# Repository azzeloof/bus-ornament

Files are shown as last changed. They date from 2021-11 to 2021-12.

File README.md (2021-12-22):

# London Bus Ornament
 A PCB holiday ornament with lots of blinking LEDs!

## Hardware
The board consists of twelve reverse-mounted LEDs [charlieplexed](https://en.wikipedia.org/wiki/Charlieplexing) and hooked up to an ATtiny85. Each LED is individually addressable, even though only four of the ATtiny's pins are being used (Charlieplexing is magic)! The board also has a pushbutton for switching between modes. The ornament is powered via two CR2025 batteries which feed a 3.3V buck converter.

The design works as-is, but there's an issue. When the programmer is hooked up, it needs to be set to not power the PCB. If it does power the boar,d it will immediatley fry the buck converter. To get around this, I cut the VCC trace to the ICSP and connected that pin to the unused pin of the power switch via a bodged wire. 

## Firmware
The ATtiny is programmed using the PlatformIO framework. Before programming, you need to write an Arduino bootloader to the chip using the Arduino IDE. When burning the bootloader, here are the settings we used:

+ Chip: "ATtiny85" (from the ATtiny Core board library)
+ Clock: "8 MHz (internal)"
+ B.O.D: "B.O.D. Disabled"
+ Timer 1 Clock: "CPU"
+ LTO (1.6.11+ only): "Disabled"

The code is adapted from the wonderful work of David Johnson-Davies, published at http://www.technoblogy.com/show?2H0K.

To program the chips, we used SparkFun's [Pocket AVR Programmer](https://www.sparkfun.com/products/9825), but you should be able to use any programmer compatibe with the ATtiny85 (or just use an Arduino Uno!).

## Version History
Release 1.0 will represent the bus ornaments as we initially made and distributed them. Once it is released, maybe we'll improve some stuff (but any hardware improvements will be untested).

## Warning
Electricity creates heat, and excess heat around something like a Christmas tree can cause big problems. Use at your own risk! The designs here have only been minimally tested and are absolutley not guarenteed to be safe.

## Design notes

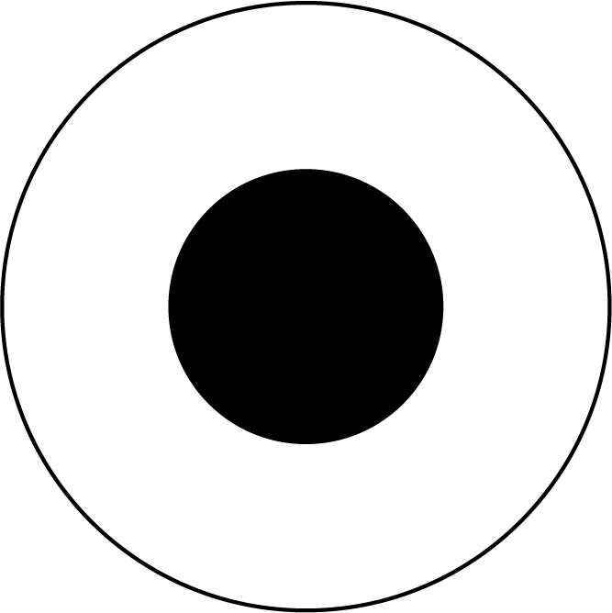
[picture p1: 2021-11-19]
hardware/artwork/wheel_hub.png

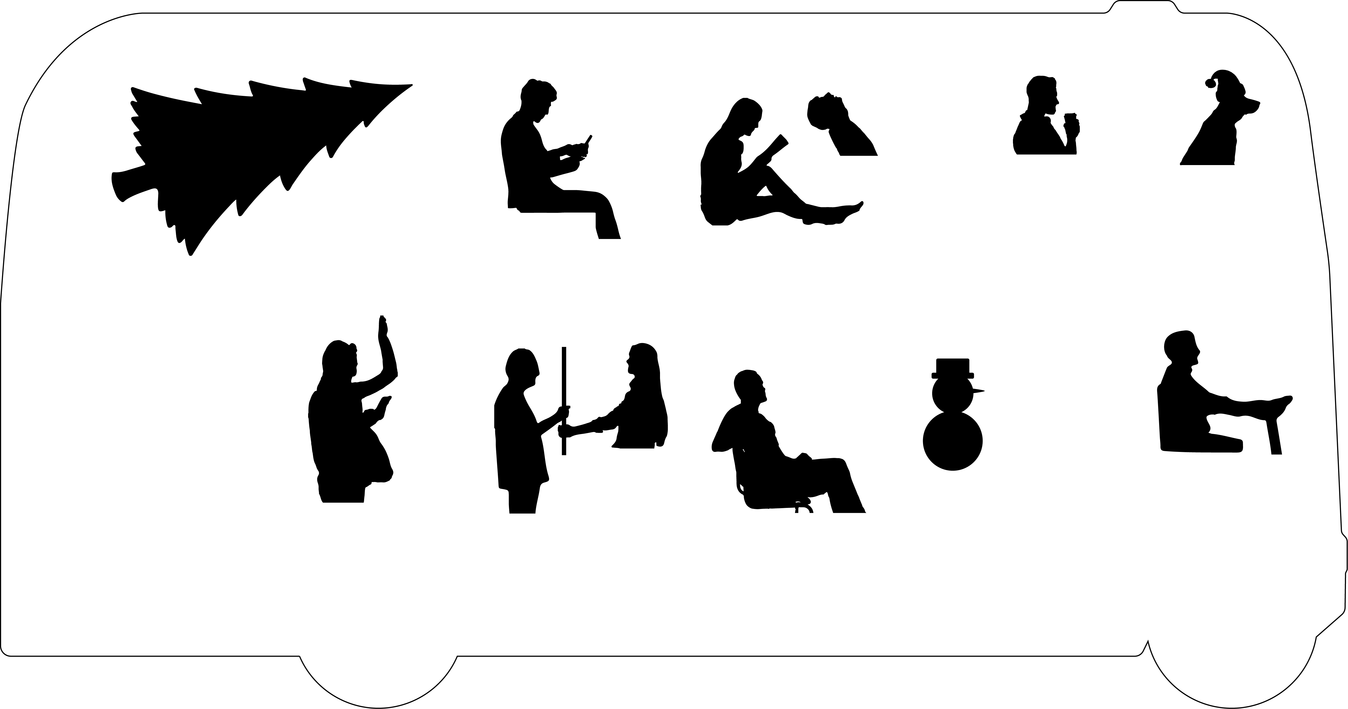
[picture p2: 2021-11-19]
hardware/artwork/inner_copper_art.png

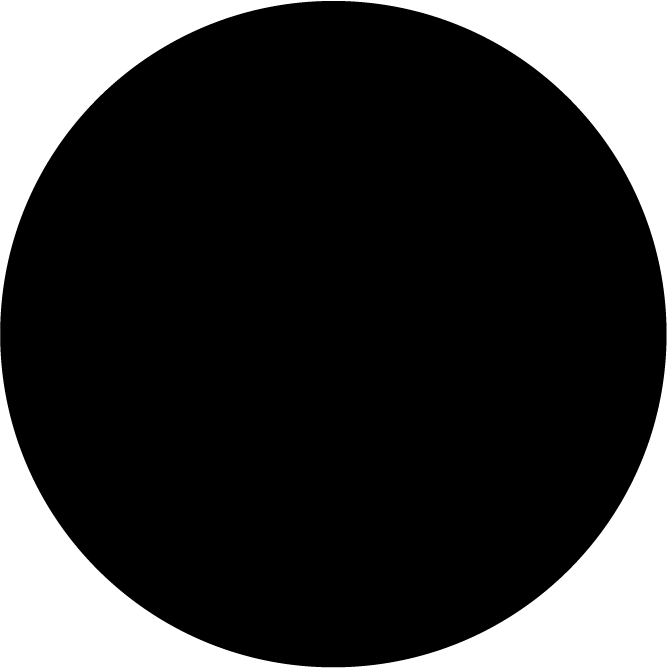
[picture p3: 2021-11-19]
hardware/artwork/wheel.png

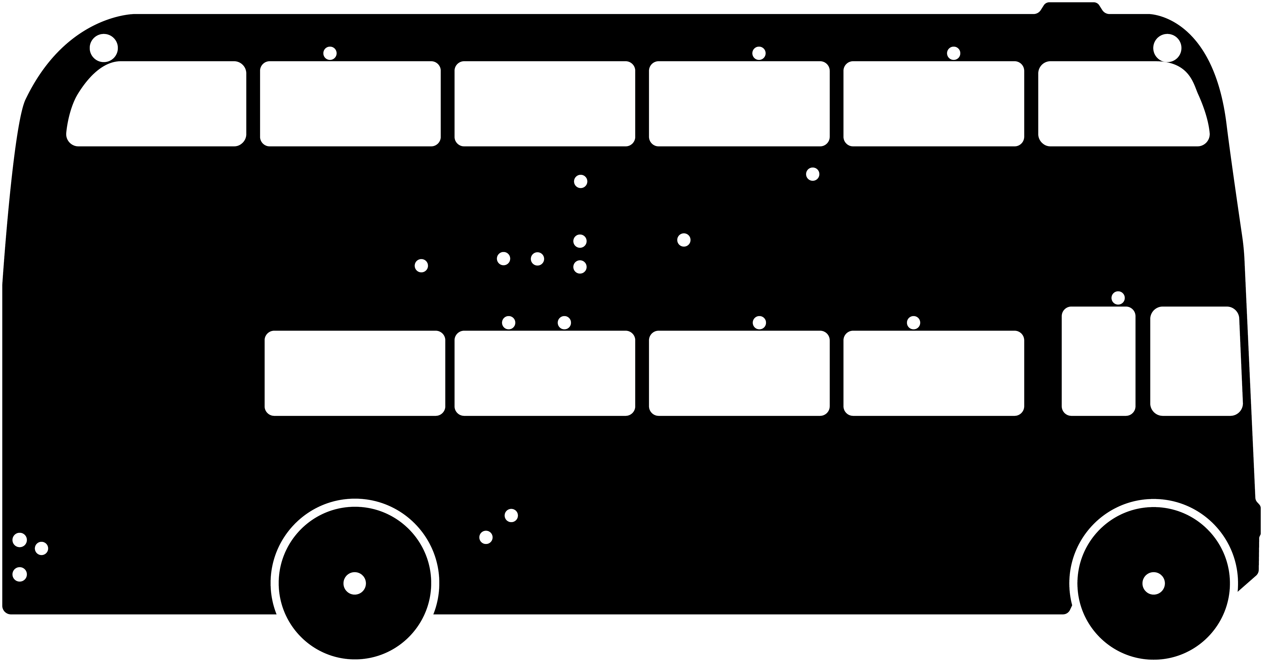
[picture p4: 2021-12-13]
hardware/artwork/copper_front.png

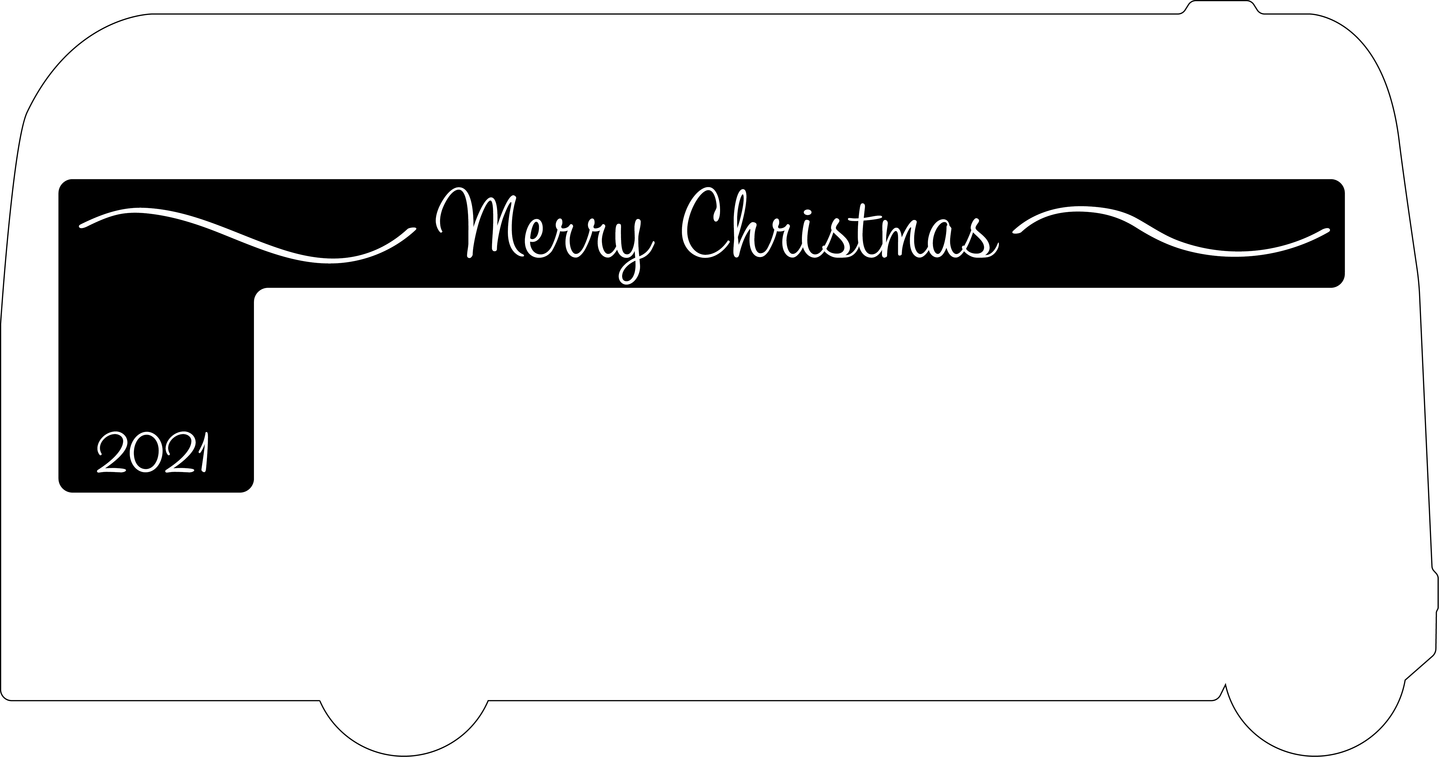
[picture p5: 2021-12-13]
hardware/artwork/silkscreen_front.png

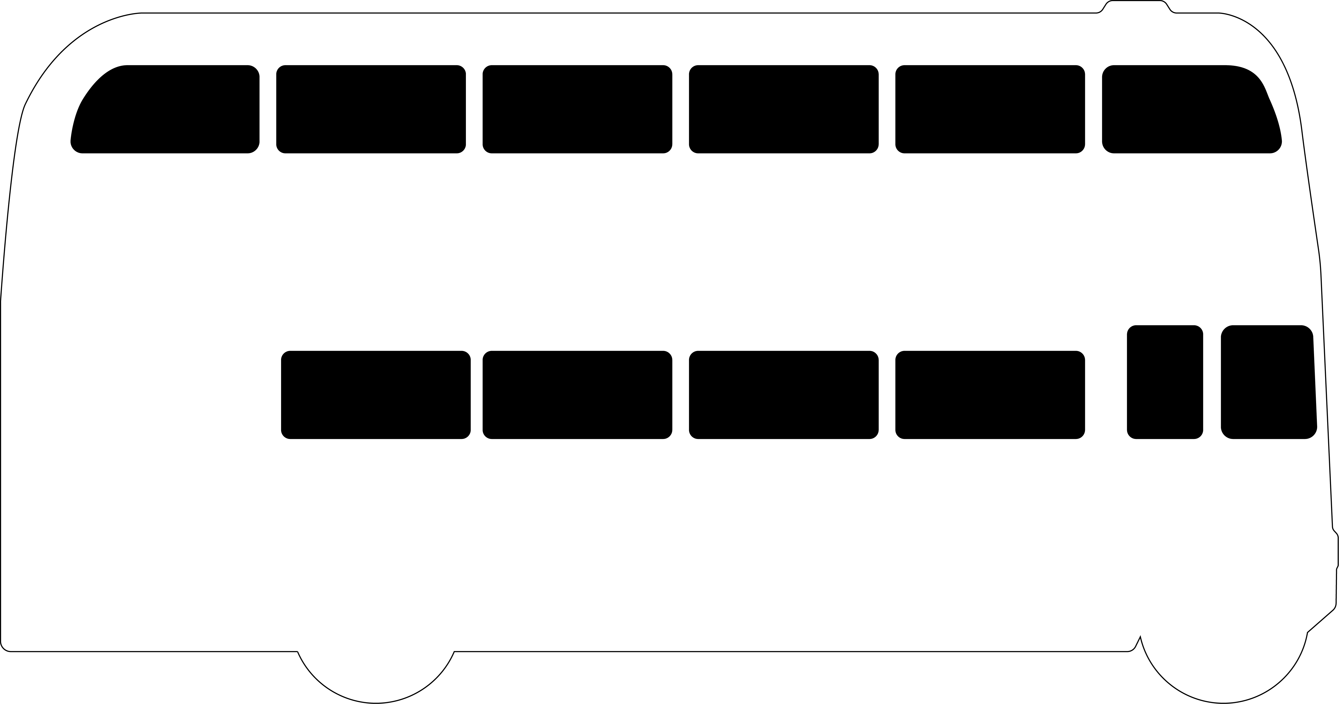
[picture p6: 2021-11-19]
hardware/artwork/mask_front.png

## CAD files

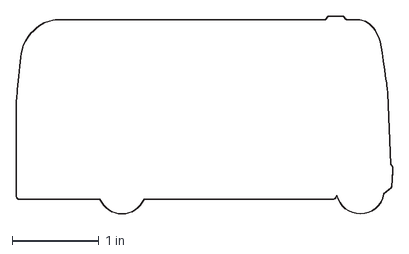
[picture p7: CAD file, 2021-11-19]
hardware/artwork/edge.dxf
4.33 x 2.28 in

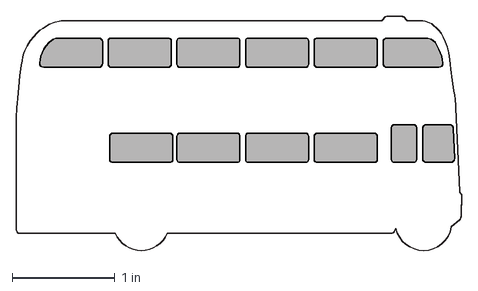
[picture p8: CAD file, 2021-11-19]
hardware/artwork/mask_front.dxf
4.33 x 2.28 in

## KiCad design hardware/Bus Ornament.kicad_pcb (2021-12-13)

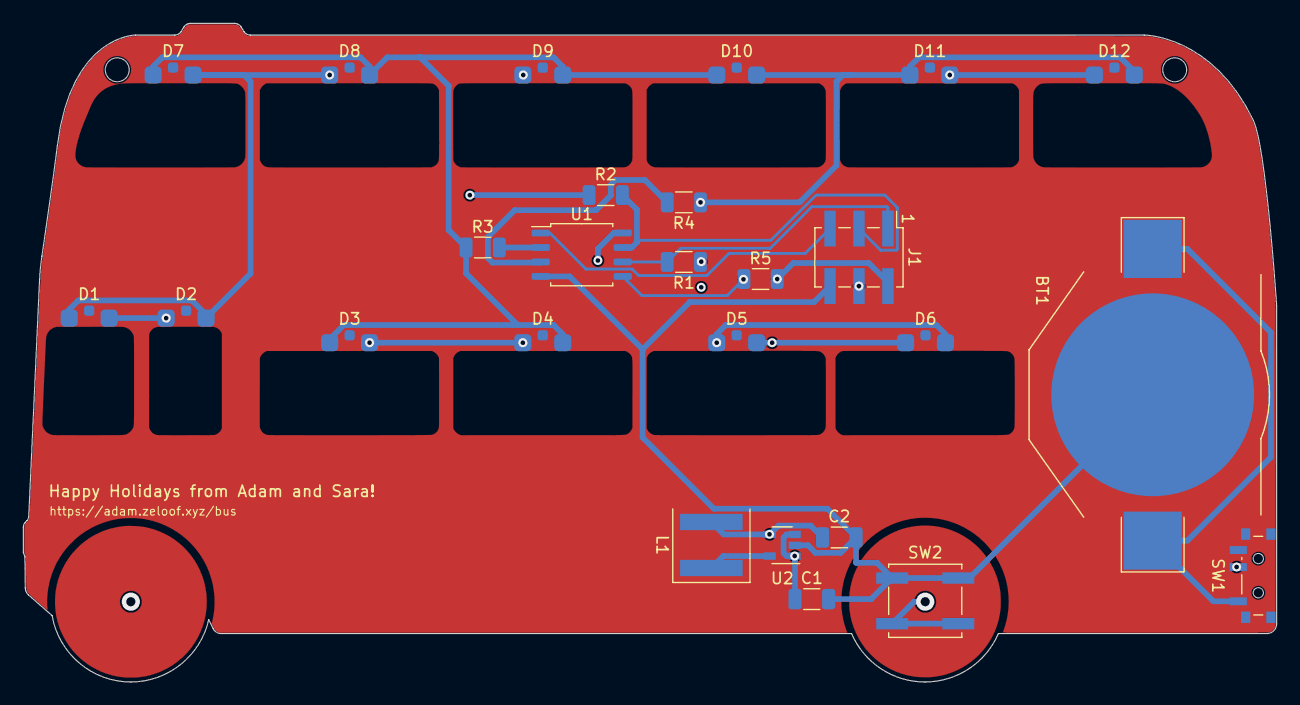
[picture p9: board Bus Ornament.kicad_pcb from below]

Board: 4 copper layers, 110.0 x 57.8 mm, 26 parts (26 on the bottom side), 15 nets.

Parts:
BT1: Battery; BatteryHolder_Keystone_3002_1x2032
C1, C2: C; C_1206_3216Metric
D1, D2, D3, D4, D5, D6, D7, D8, D9, D10, D11, D12: LED; IN-S121AS
J1: Conn_02x03_Odd_Even; PinHeader_2x03_P2.54mm_Vertical_SMD
L1: L; L_Coilcraft_XAL60xx_6.36x6.56mm
R1, R2, R3, R4, R5: R_US; R_1206_3216Metric
SW1: SW_SPST; SW_SPDT_PCM12
SW2: SW_Push; SW_Push_1P1T_NO_CK_KSC6xxJ
U1: ATtiny85-20PU; SOIC-8_5.23x5.23mm_P1.27mm
U2: TPS62203DBV; SOT-23-5

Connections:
+BATT: BT1.1, SW1.1
GND: BT1.2, C1.2, C2.2, J1.6, SW2.2, U1.4, U2.2
MISO: J1.1, R1.2, U1.6
MOSI: J1.4, R5.1, SW2.1, U1.5
unnamed: C1.1, SW1.2, U2.1, U2.3
unnamed: D1.1, D2.2, D7.2, D8.1, D11.2, D12.1, R2.1
unnamed: D1.2, D2.1, D3.2, D4.1, D5.2, D6.1, R1.1
unnamed: D3.1, D4.2, D7.1, D8.2, D9.2, D10.1, R3.1
unnamed: D5.1, D6.2, D9.1, D10.2, D11.1, D12.2, R4.1
unnamed: L1.1, U2.5
unnamed: R3.2, U1.2
unnamed: R4.2, U1.3
RST: J1.5, U1.1
SCK: J1.3, R2.2, U1.7
VCC: C2.1, J1.2, L1.2, R5.2, U1.8, U2.4

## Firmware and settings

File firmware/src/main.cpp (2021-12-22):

/*
 * London Bus Christmas Ornament
 * 
 * Sara Adkins & Adam Zeloof - November 2021
 * 
 * PWM code adapted from David Johnson-Davies - www.technoblogy.com - 19th February 2017
 * http://www.technoblogy.com/show?2H0K
 */

#include "Arduino.h"
#include "modeButton.h"
#include "leds.h"
#include "scrollingSequentialAnimation.h"
#include "singleSequentialAnimation.h"
#include "randomAnimation.h"

// Timer/Counter1 overflow interrupt
ISR(TIM1_COMPA_vect) {
  static uint8_t row, ramp, column, bits, colbit;
  ramp = (ramp+1) & 0x3F;             // Count from 0 to 63
  if (ramp == 0) {
    bits = 0x07; //0000111                    // All on
    column = (column + 1) & 0x03; // Count from 0 to 3
    row = column * 3;               //0 3 6 9
    colbit = 1<<(column+0); // 0b0001 0b0010 0b0100 0b1000
  }

  //check if check col has reached its ramp
  if (Level[row] == ramp) bits = bits & 0x06; // 00000110, mask out pos 0
  if (Level[row+1] == ramp) bits = bits & 0x05; // 00000101, mask out pos 1
  if (Level[row+2] == ramp) bits = bits & 0x03; // 00000011, mask out pos 2
  
  uint8_t mask = colbit - 1; 
  
  uint8_t outputs = (bits & mask) | (bits & ~mask)<<1;
  DDRB = (outputs | colbit) << 1;
  PORTB = (outputs) << 1;
}

void setup() {
  // Set up Timer/Counter1 to multiplex the LEDs
  TCCR1 = 1<<CTC1 | 2<<CS10;          // Divide by 2
  GTCCR = 0;                          // No PWM
  OCR1A = 0;
  OCR1C = 250-1;                      // 16kHz
  TIMSK = TIMSK | 1<<OCIE1A;          // Compare Match A interrupt

  setupButton();
  setupLeds();
}

void allOnProgram()
{
  allOn();
  checkButton();
}

void allOffProgram()
{
  clearLeds();
  checkButton();
}

uint32_t delayMS = 4000;

void loop () {
  switch(mode) {   
    case 0:
      randomProgram(delayMS);
      break; 
    case 1:
      allOnProgram();
      break;
    case 2:
      singleSequentialProgram(delayMS);
      break;
    //case 3:
    //  scrollingSequentialProgram(4, delayMS);
    //  break;
    default:
      allOffProgram();
      break;
  }
}

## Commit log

2021-11-19 Design completed
    [Bus Ornament.kicad_pcb, Bus Ornament.sch, edge.dxf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]
2021-11-19 Generated gerbers
    [Bus Ornament-B_Cu.gbl, Bus Ornament-B_Mask.gbs, Bus Ornament-B_Paste.gbp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]
2021-11-19 Repo Reorg and Cleanup
    [Bus Ornament-B_Cu.gbl, Bus Ornament-B_Mask.gbs, Bus Ornament-B_Paste.gbp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]
2021-11-26 Firmware written but untested
    [Bus Ornament.sch]
2021-12-13 Crated front fill, ordered new boards
    [Bus Ornament-B_Cu.gbl, Bus Ornament-B_Mask.gbs, Bus Ornament-B_Paste.gbp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]
